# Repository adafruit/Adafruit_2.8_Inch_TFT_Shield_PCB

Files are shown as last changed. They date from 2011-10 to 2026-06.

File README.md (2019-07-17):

# 2.8" TFT Touch Shield for Arduino 

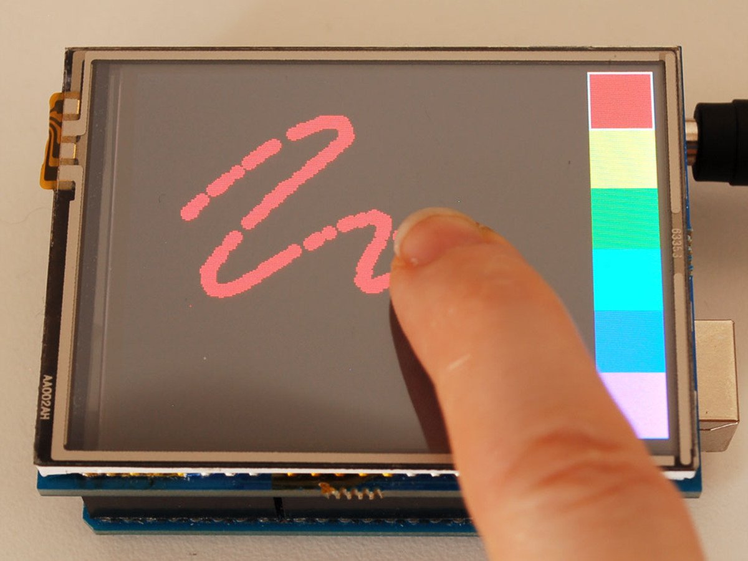
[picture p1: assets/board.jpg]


We've discontinued this version of the shield (which was expensive and difficult to make) and [replaced it with a version 2: its got a better price, uses way fewer pins, is Mega/Leonardo compatible and has a great touchscreen controller built in. Wow! Check it out here.](http://www.adafruit.com/products/1651)

Spice up your Arduino project with a beautiful large touchscreen display shield with built in microSD card connection. This TFT display is big (2.8" diagonal) bright (4 white-LED backlight) and colorful (18-bit 262,000 different shades)! 240x320 pixels with individual pixel control. It has way more resolution than a black and white 128x64 display. As a bonus, this display has a resistive touchscreen attached to it already, so you can detect finger presses anywhere on the screen.

__The shield is fully assembled, tested and ready to go. No wiring, no soldering! Simply plug it in and load up our library - you'll have it running in under 10 minutes!__ Works best with any classic Arduino (UNO/Duemilanove/Diecimila). This shield does work with the Mega Arduinos __but its going to be half the speed of the Uno-type boards__ because of the way the Mega rearranges all the pins (there is no way to get around this!) This shield is not Leonardo-compatible

This display shield has a controller built into it with RAM buffering, so that almost no work is done by the microcontroller. The shield does require a lot of pins: 12 lines total for the display, 13 total if you use the microSD card

[Of course, we wouldn't just leave you with a datasheet and a "good luck!" - we've written a full open source graphics library that can draw pixels, lines, rectangles, circles and text. We also have a touch screen library that detects x, y and z (pressure) and example code to demonstrate all of it. The code is written for Arduino but can be easily ported to your favorite microcontroller!](http://learn.adafruit.com/2-8-tft-touch-shield).

If you are not using an Arduino-shaped microcontroller, [check out our 2.8" TFT breakout board which can be easily wired up to any processor](http://www.adafruit.com/products/335) the breakout board version does not have microSD holder.

### TECHNICAL DETAILS

- 2.8" diagonal LCD TFT display
- 240x320 resolution, 18-bit (262,000) color
- ILI9325 (datasheet) or ILI9328 (datasheet) or HX8347 (datasheet) controller with built in video RAM buffer
- 8 bit digital interface, plus 4 control lines
- Uses digital pins 5-13 and analog 0-3. That means you can use digital pins 2, 3 and analog 4 and 5. Pin 12 is available if not using the microSD
- Works with any Arduino '328 or Mega (Leonardo not supported yet)
- 5V compatible! Use with 3.3V or 5V logic
- Onboard 3.3V @ 300mA LDO regulator
- 4 white LED backlight. On by default but you can connect the transistor to a digital pin for backlight control
- 4-wire resistive touchscreen

### License

Adafruit invests time and resources providing this open source design, please support Adafruit and open-source hardware by purchasing products from [Adafruit](https://www.adafruit.com)!

Designed by Limor Fried/Ladyada for Adafruit Industries.

Creative Commons Attribution/Share-Alike, all text above must be included in any redistribution. See license.txt for additional details.

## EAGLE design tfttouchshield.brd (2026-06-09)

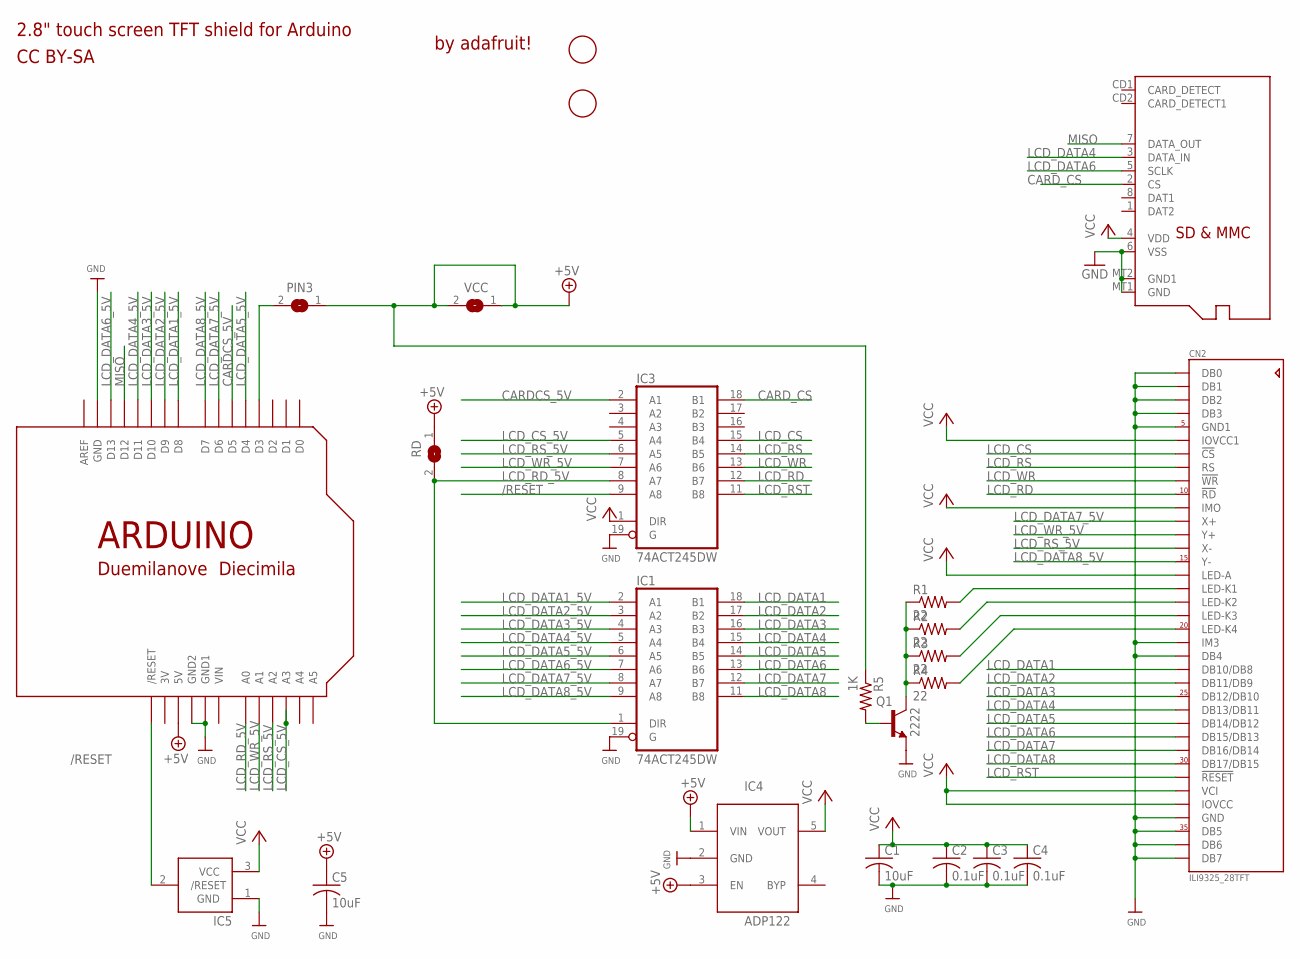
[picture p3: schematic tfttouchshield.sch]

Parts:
C1, C5: 10uF; C0805K
C2, C3, C4: 0.1uF; C0805K
CN2: ILI9325_28TFT; ILI9325_28INCH_TS
IC1, IC3: 74ACT245DW; SO20W
IC4: ADP122; SOT23-5L
IC5: AXP083-SAG; SOT23
PIN3: SJ
Q1: 2222; SOT23-BEC
R1, R2, R3, R4: 22; R0805
R5: 1K; R0805
RD: SJ
U$2: ARDUINO-NOHOLE
U$3: MICROSD
U$10, U$11: FIDUCIAL; FIDUCIAL_1MM
VCC: SJ

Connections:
3V: U$2.3V
+5V: C5.1, IC4.1 (VIN), IC4.3 (EN), PIN3.1, R5.1, RD.1, U$2.5V, VCC.1, VCC.2
/RESET: IC3.9 (A8), IC5.2 (/RESET), U$2.RESET (/RESET)
CARDCS_5V: IC3.2 (A1), U$2.D5
CARD_CS: IC3.18 (B1), U$3.2 (CS)
GND: C1.2, C2.2, C3.2, C4.2, C5.2, CN2.1 (DB0), CN2.2 (DB1), CN2.3 (DB2), CN2.4 (DB3), CN2.5 (GND1), CN2.21 (IM3), CN2.22 (DB4), CN2.34 (GND), CN2.35 (DB5), CN2.36 (DB6), CN2.37 (DB7), IC1.10 (GND), IC1.19 (G), IC3.10 (GND), IC3.19 (G), IC4.2 (GND), IC5.1 (GND), Q1.E, U$2.GND, U$2.GND1, U$2.GND2, U$3.6 (VSS), U$3.MT1 (GND), U$3.MT2 (GND1)
LCD_CS: CN2.7 (!CS), IC3.15 (B4)
LCD_CS_5V: IC3.5 (A4), U$2.A3
LCD_DATA1: CN2.23 (DB10/DB8), IC1.18 (B1)
LCD_DATA1_5V: IC1.2 (A1), U$2.D8
LCD_DATA2: CN2.24 (DB11/DB9), IC1.17 (B2)
LCD_DATA2_5V: IC1.3 (A2), U$2.D9
LCD_DATA3: CN2.25 (DB12/DB10), IC1.16 (B3)
LCD_DATA3_5V: IC1.4 (A3), U$2.D10
LCD_DATA4: CN2.26 (DB13/DB11), IC1.15 (B4), U$3.3 (DATA_IN)
LCD_DATA4_5V: IC1.5 (A4), U$2.D11
LCD_DATA5: CN2.27 (DB14/DB12), IC1.14 (B5)
LCD_DATA5_5V: IC1.6 (A5), U$2.D4
LCD_DATA6: CN2.28 (DB15/DB13), IC1.13 (B6), U$3.5 (SCLK)
LCD_DATA6_5V: IC1.7 (A6), U$2.D13
LCD_DATA7: CN2.29 (DB16/DB14), IC1.12 (B7)
LCD_DATA7_5V: CN2.12 (X+), IC1.8 (A7), U$2.D6
LCD_DATA8: CN2.30 (DB17/DB15), IC1.11 (B8)
LCD_DATA8_5V: CN2.15 (Y-), IC1.9 (A8), U$2.D7
LCD_RD: CN2.10 (!RD), IC3.12 (B7)
LCD_RD_5V: IC1.1 (DIR), IC3.8 (A7), RD.2, U$2.A0
LCD_RS: CN2.8 (RS), IC3.14 (B5)
LCD_RST: CN2.31 (!RESET), IC3.11 (B8)
LCD_RS_5V: CN2.14 (X-), IC3.6 (A5), U$2.A2
LCD_WR: CN2.9 (!WR), IC3.13 (B6)
LCD_WR_5V: CN2.13 (Y+), IC3.7 (A6), U$2.A1
MISO: U$2.D12, U$3.7 (DATA_OUT)
unnamed: CN2.20 (LED-K4), R4.2
unnamed: CN2.17 (LED-K1), R1.2
unnamed: CN2.18 (LED-K2), R2.2
unnamed: CN2.19 (LED-K3), R3.2
unnamed: Q1.C, R1.1, R2.1, R3.1, R4.1
unnamed: PIN3.2, U$2.D3
unnamed: Q1.B, R5.2
VCC: C1.1, C2.1, C3.1, C4.1, CN2.6 (IOVCC1), CN2.11 (IMO), CN2.16 (LED-A), CN2.32 (VCI), CN2.33 (IOVCC), IC1.20 (VCC), IC3.1 (DIR), IC3.20 (VCC), IC4.5 (VOUT), IC5.3 (VCC), U$3.4 (VDD)
VIN: U$2.VIN

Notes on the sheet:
2.8" touch screen TFT shield for Arduino
by adafruit!
CC BY-SA

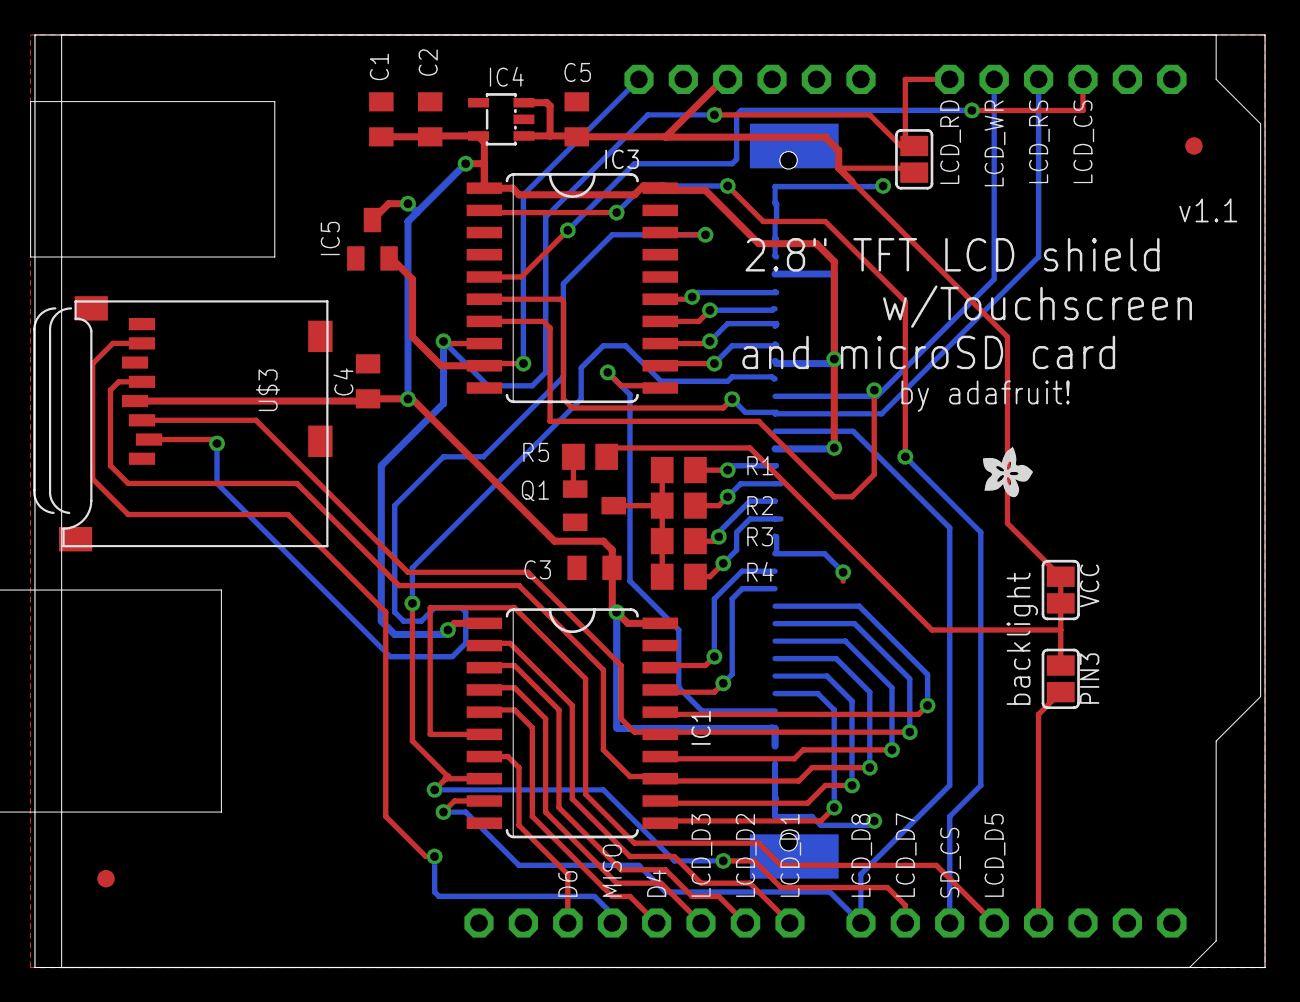
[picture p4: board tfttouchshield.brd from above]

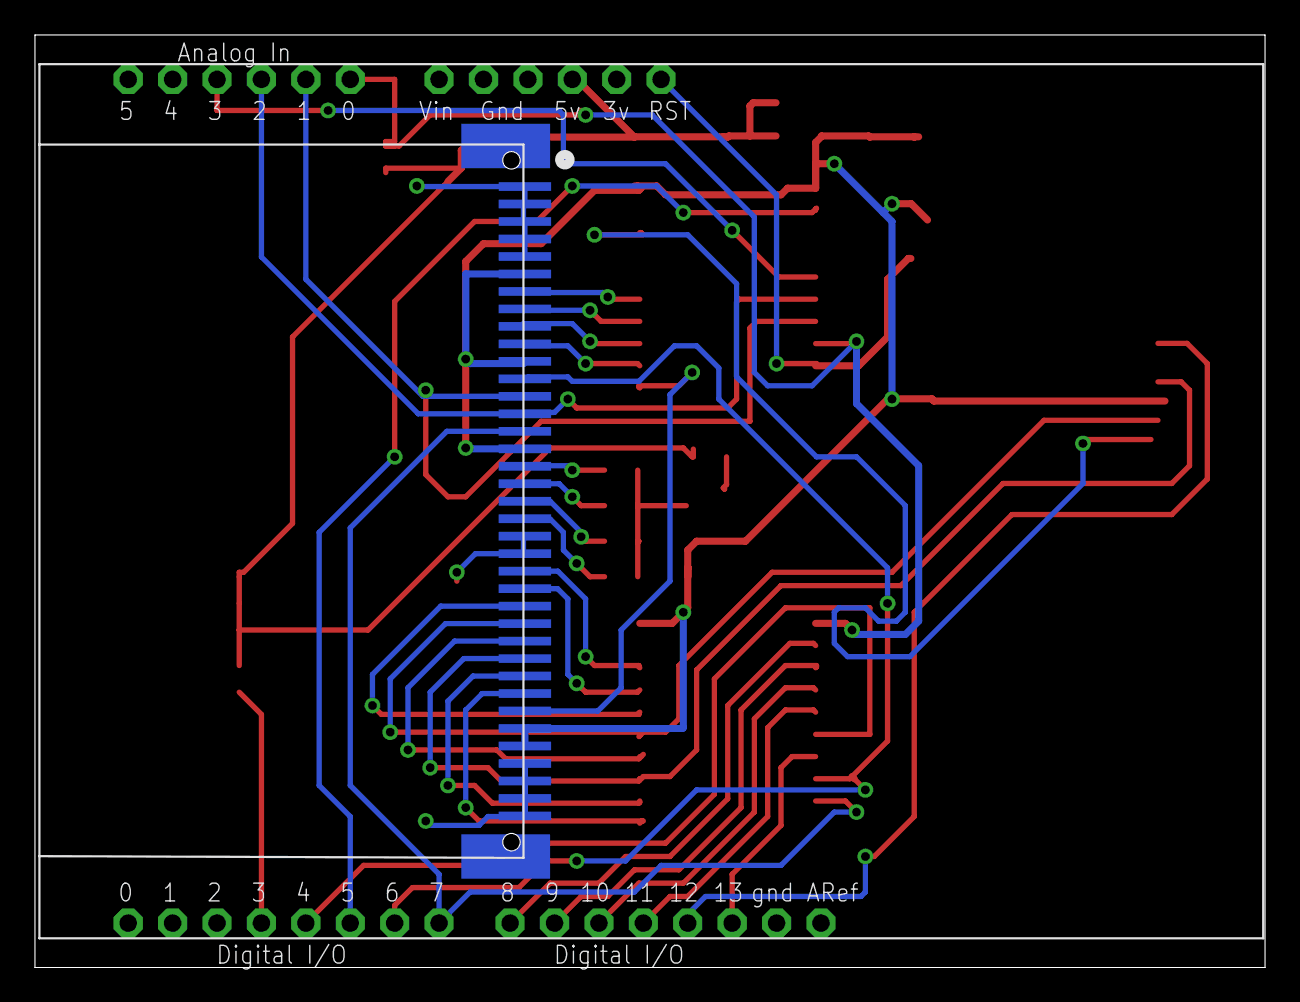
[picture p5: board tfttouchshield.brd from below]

Board: 2 copper layers, 70.4 x 53.3 mm, 25 parts (2 on the bottom side), 39 nets.

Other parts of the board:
U$7: ADAFRUIT200MIL
U$9: OSHWLOGO_TOL_0.2

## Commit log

2011-06-08 schem print
2011-10-18 Updated to latest minor rev, with better routing, and a jumper on RD
    [tfttouchshield.brd, tfttouchshield.sch]
2026-06-03 update file format to XML
    [tfttouchshield.brd, tfttouchshield.sch]
